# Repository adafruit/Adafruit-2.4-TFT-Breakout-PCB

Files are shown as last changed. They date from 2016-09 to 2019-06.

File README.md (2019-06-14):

## Adafruit 2.4 TFT Breakout PCB

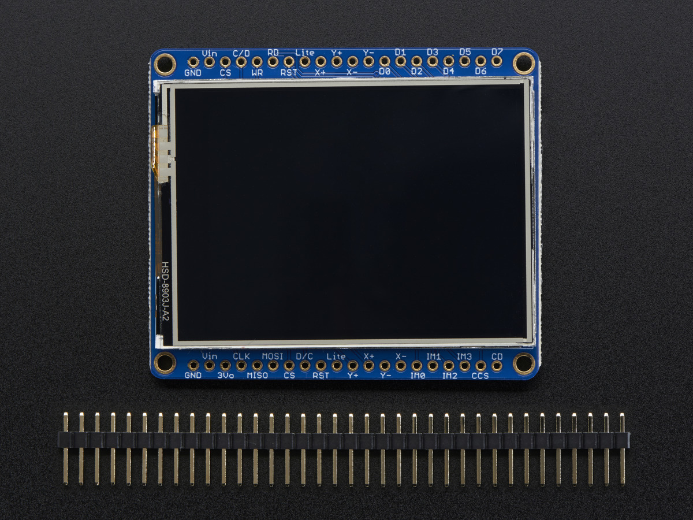
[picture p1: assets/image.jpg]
<a href="http://www.adafruit.com/products/2478"><br/>
Click here to purchase one from the Adafruit shop</a>

PCB files for the Adafruit 2.4" TFT Breakout. Format is EagleCAD schematic and board layout
* https://www.adafruit.com/product/2478

### DESCRIPTION
Add some jazz & pizzazz to your project with a color touchscreen LCD. This TFT display is 2.4" diagonal with a bright (4 white-LED) backlight and it's colorful! 240x320 pixels with individual RGB pixel control, this has way more resolution than a black and white 128x64 display.

As a bonus, this display has a resistive touchscreen attached to it already, so you can detect finger presses anywhere on the screen.

If you need a larger touchscreen, check out the 2.8" diagonal or 3.5" diagonal TFT breakouts. For a smaller display, see our non-touch 2.2" or 1.8" or 1.44" diagonal TFTs

This display has a controller built into it with RAM buffering, so that almost no work is done by the microcontroller. The display can be used in two modes: 8-bit or SPI. For 8-bit mode, you'll need 8 digital data lines and 4 or 5 digital control lines to read and write to the display (12 lines total). SPI mode requires only 5 pins total (SPI data in, data out, clock, select, and d/c) but is slower than 8-bit mode.

In addition, 4 pins are required for the touch screen (2 digital, 2 analog) or you can purchase and use our resistive touchscreen controller (not included) to use I2C or SPI.

### License

Adafruit invests time and resources providing this open source design, please support Adafruit and open-source hardware by purchasing products from [Adafruit.com](https://www.adafruit.com)!

Creative Commons Attribution, Share-Alike license, check license.txt for more information All text above must be included in any redistribution - 
See license.txt for more information.

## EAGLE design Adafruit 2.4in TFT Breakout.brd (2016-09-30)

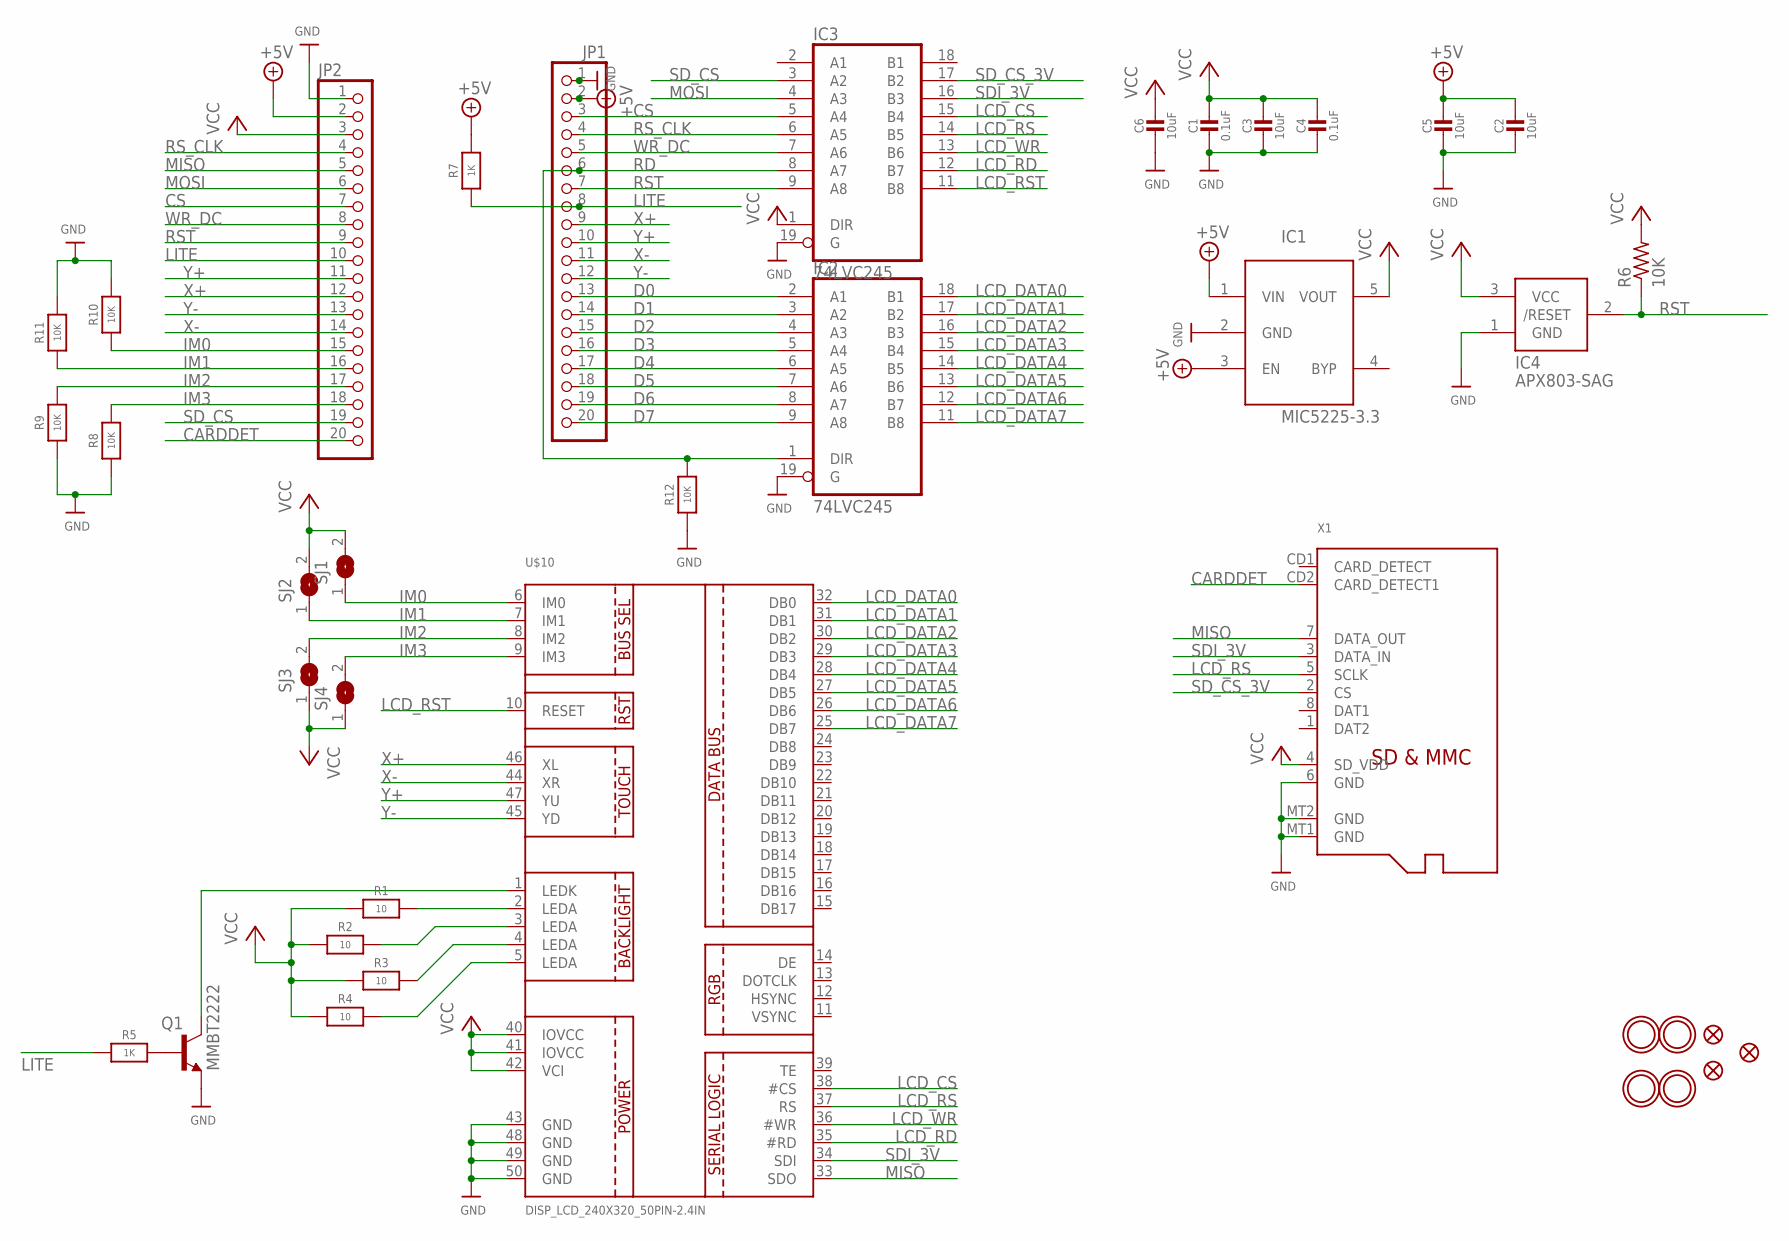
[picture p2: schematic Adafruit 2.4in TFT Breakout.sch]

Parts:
C1, C4: 0.1uF; 0805-NO
C2, C3, C5, C6: 10uF; 0805-NO
IC1: MIC5225-3.3; SOT23-5L
IC2, IC3: 74LVC245; SO20W
IC4: APX803-SAG; SOT23
JP1, JP2: HEADER-1X20ROUND; 1X20_ROUND
Q1: MMBT2222; SOT23-BEC
R1, R2, R3, R4: 10; 0805-NO
R5, R7: 1K; 0805-NO
R6: 10K; R0805
R8, R9, R10, R11, R12: 10K; 0805-NO
SJ1, SJ2, SJ3, SJ4: SOLDERJUMPER; SOLDERJUMPER_ARROW_NOPASTE
U$7, U$15, U$16, U$17: MOUNTINGHOLE2.5; MOUNTINGHOLE_2.5_PLATED
U$9, U$11, U$23: FIDUCIAL""; FIDUCIAL_1MM
U$10: DISP_LCD_240X320_50PIN-2.4IN; TFT_2.4IN_240X320_50PIN
X1: MICROSD

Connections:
+3V: C1.1, C3.1, C4.1, C6.1, IC1.5 (VOUT), IC2.20 (VCC), IC3.1 (DIR), IC3.20 (VCC), IC4.3 (VCC), JP2.3, R1.1, R2.1, R3.1, R4.1, R6.2, SJ1.2, SJ2.2, SJ3.1, SJ4.1, U$10.40 (IOVCC), U$10.41 (IOVCC), U$10.42 (VCI), X1.4 (SD_VDD)
CARDDET: JP2.20, X1.CD2 (CARD_DETECT1)
CS: IC3.5 (A4), JP1.3, JP2.7
D0: IC2.2 (A1), JP1.13
D1: IC2.3 (A2), JP1.14
D2: IC2.4 (A3), JP1.15
D3: IC2.5 (A4), JP1.16
D4: IC2.6 (A5), JP1.17
D5: IC2.7 (A6), JP1.18
D6: IC2.8 (A7), JP1.19
D7: IC2.9 (A8), JP1.20
GND: C1.2, C2.2, C3.2, C4.2, C5.2, C6.2, IC1.2 (GND), IC2.10 (GND), IC2.19 (G), IC3.10 (GND), IC3.19 (G), IC4.1 (GND), JP1.1, JP2.1, Q1.E, R8.1, R9.1, R10.2, R11.2, R12.1, U$10.43 (GND), U$10.48 (GND), U$10.49 (GND), U$10.50 (GND), X1.6 (GND), X1.MT1 (GND), X1.MT2 (GND)
IM0: JP2.15, R10.1, SJ1.1, U$10.6 (IM0)
IM1: JP2.16, R11.1, SJ2.1, U$10.7 (IM1)
IM2: JP2.17, R9.2, SJ3.2, U$10.8 (IM2)
IM3: JP2.18, R8.2, SJ4.2, U$10.9 (IM3)
LCD_CS: IC3.15 (B4), U$10.38 (#CS)
LCD_DATA0: IC2.18 (B1), U$10.32 (DB0)
LCD_DATA1: IC2.17 (B2), U$10.31 (DB1)
LCD_DATA2: IC2.16 (B3), U$10.30 (DB2)
LCD_DATA3: IC2.15 (B4), U$10.29 (DB3)
LCD_DATA4: IC2.14 (B5), U$10.28 (DB4)
LCD_DATA5: IC2.13 (B6), U$10.27 (DB5)
LCD_DATA6: IC2.12 (B7), U$10.26 (DB6)
LCD_DATA7: IC2.11 (B8), U$10.25 (DB7)
LCD_RD: IC3.12 (B7), U$10.35 (#RD)
LCD_RS: IC3.14 (B5), U$10.37 (RS), X1.5 (SCLK)
LCD_RST: IC3.11 (B8), U$10.10 (RESET)
LCD_WR: IC3.13 (B6), U$10.36 (#WR)
LITE: JP1.8, JP2.10, R5.1, R7.1
MISO: JP2.5, U$10.33 (SDO), X1.7 (DATA_OUT)
MOSI: IC3.4 (A3), JP2.6
unnamed: R4.2, U$10.5 (LEDA)
unnamed: R1.2, U$10.2 (LEDA)
unnamed: R2.2, U$10.3 (LEDA)
unnamed: R3.2, U$10.4 (LEDA)
unnamed: Q1.C, U$10.1 (LEDK)
unnamed: Q1.B, R5.2
RD: IC2.1 (DIR), IC3.8 (A7), JP1.6, R12.2
RST: IC3.9 (A8), IC4.2 (/RESET), JP1.7, JP2.9, R6.1
RS_CLK: IC3.6 (A5), JP1.4, JP2.4
SDI_3V: IC3.16 (B3), U$10.34 (SDI), X1.3 (DATA_IN)
SD_CS: IC3.3 (A2), JP2.19
SD_CS_3V: IC3.17 (B2), X1.2 (CS)
VIN: C2.1, C5.1, IC1.1 (VIN), IC1.3 (EN), JP1.2, JP2.2, R7.2
WR_DC: IC3.7 (A6), JP1.5, JP2.8
X+: JP1.9, JP2.12, U$10.46 (XL)
X-: JP1.11, JP2.14, U$10.44 (XR)
Y+: JP1.10, JP2.11, U$10.47 (YU)
Y-: JP1.12, JP2.13, U$10.45 (YD)

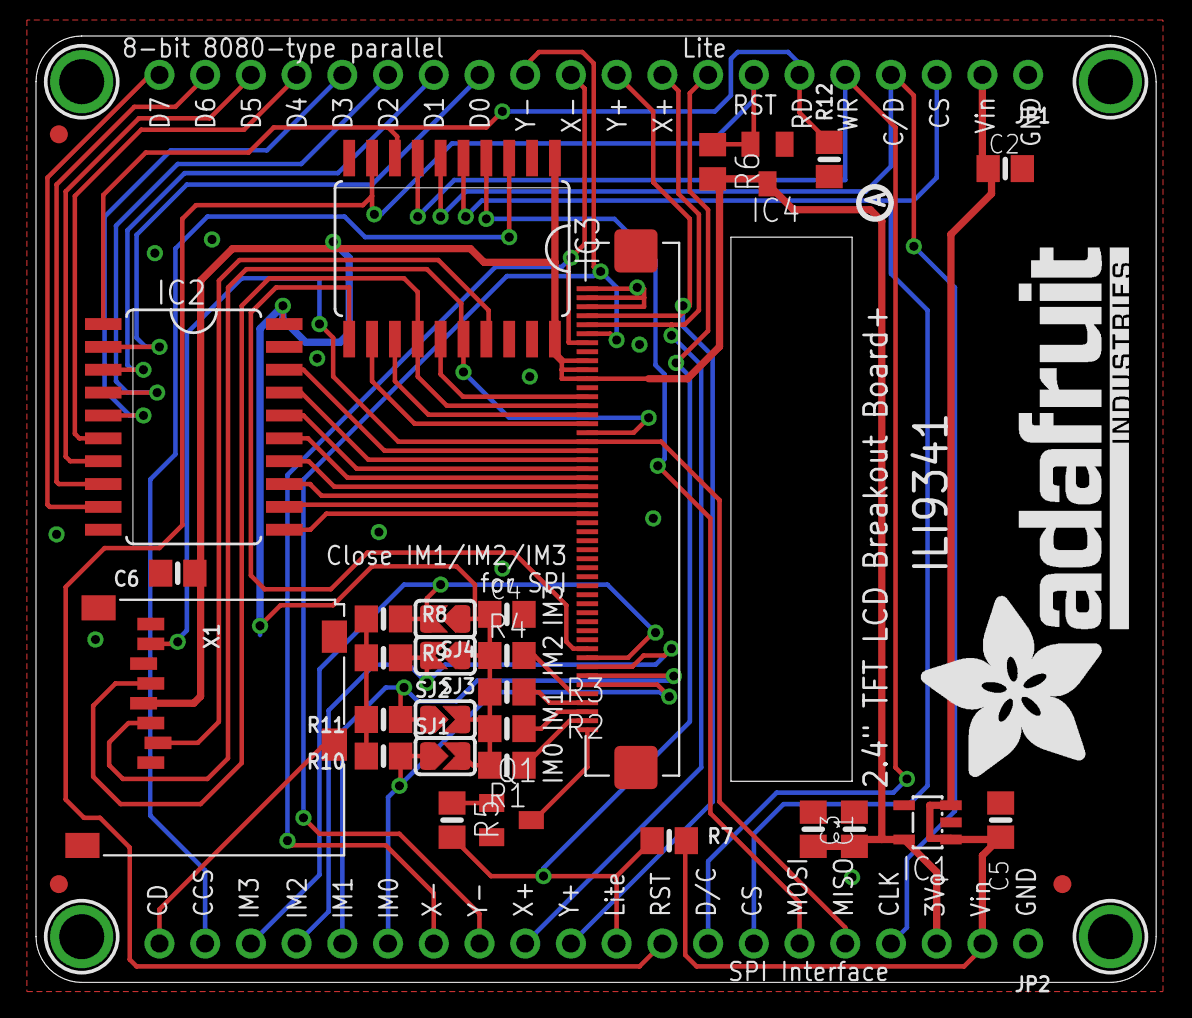
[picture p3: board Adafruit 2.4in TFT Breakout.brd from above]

Board: 2 copper layers, 62.2 x 52.6 mm, 40 parts (1 on the bottom side), 50 nets.

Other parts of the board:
U$19: ADAFRUIT_TEXT_30MM
U$26: PCBFEAT-REV-040
